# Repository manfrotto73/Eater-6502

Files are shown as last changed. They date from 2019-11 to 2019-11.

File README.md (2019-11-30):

# Eater-6502
This is a KiCad project that follows Ben Eater's 6502 video series (https://eater.net/6502). I designed the PCB from Ben's schematic.

DISCLAIMER: I am not an EE or a professional PCB designer. I am just a hobbyist who enjoys tinkering w/ electronics and computers. I have no formal training in electrical engineering. Any constructive and educational input is much appreciated.

I have addedd test points on the address and data bus for attaching the Arduino monitor.
The clock has a jumper for access to the internal 1MHz crystal or you can remove the jumper and use Ben's breadboard clock. I also have a pcb for the clock if needed (https://github.com/manfrotto73/Eater-Clock).
There is access to the 8 port "B" lines of the 6522 to attach LED's or a oscilloscope to decode the LCD data if needed. There is a footprint for a current limiting resistor pack (220R) so the LED's will not draw too much current.
I intend to socket all IC's and LED's for ease of troubleshooting or ROM update. Also the LED's are only for the first couple of programs.
Enjoy!
11/29/2019 Schematic and PCB updated to pull the BE pin high to +5V

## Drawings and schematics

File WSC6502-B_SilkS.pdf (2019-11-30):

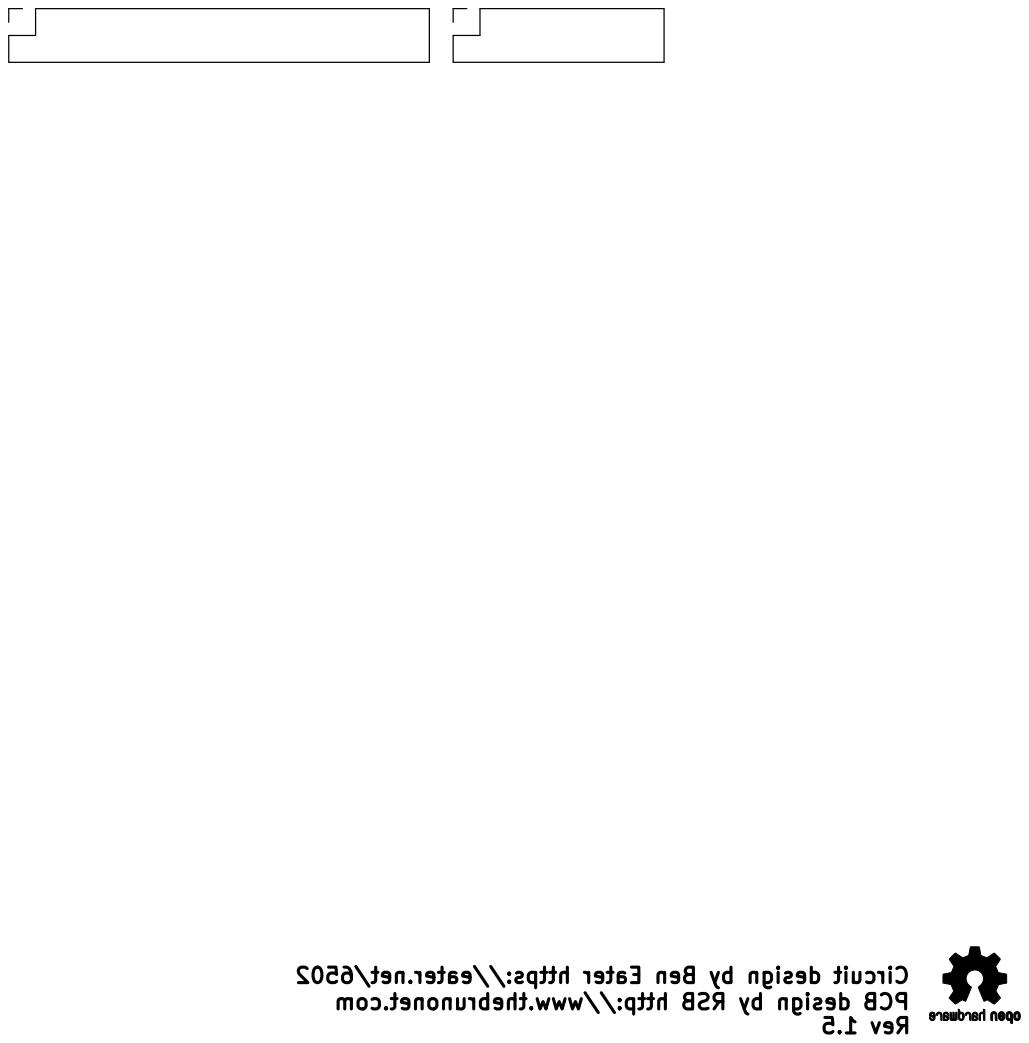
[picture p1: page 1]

Rev 1.5 Circuit design by Ben Eater https://eater.net/6502

PCB design by RSB http://www.thebrunonet.com

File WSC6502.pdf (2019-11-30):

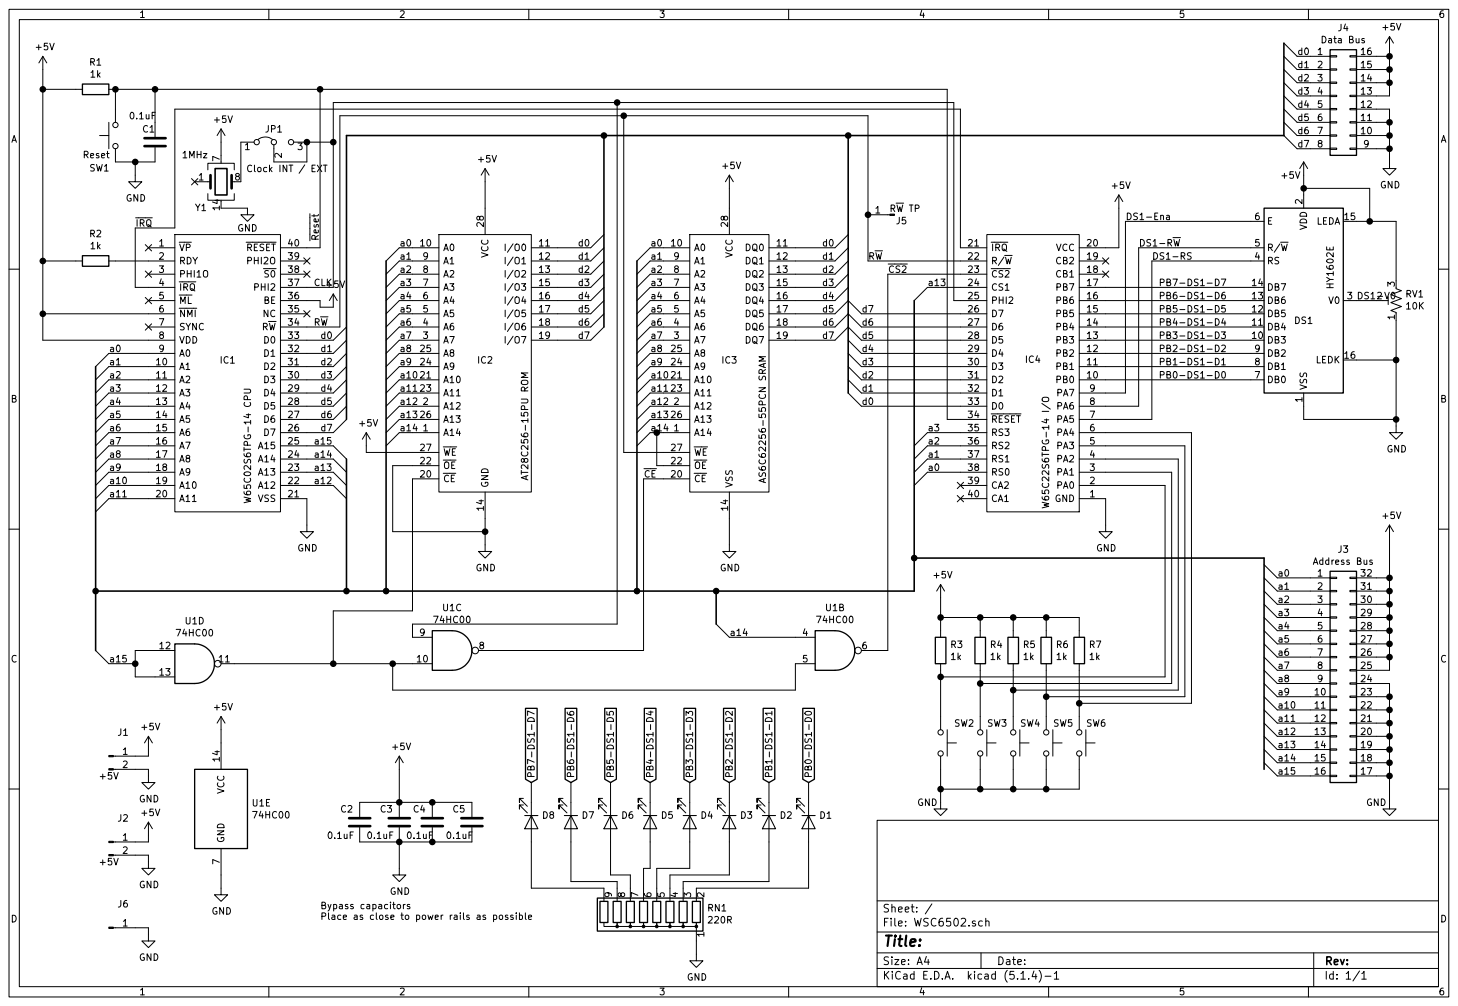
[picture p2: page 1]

Id: 1/1 Title: File: WSC6502.sch Sheet: / D7 GND GND

Place as close to power rails as possible

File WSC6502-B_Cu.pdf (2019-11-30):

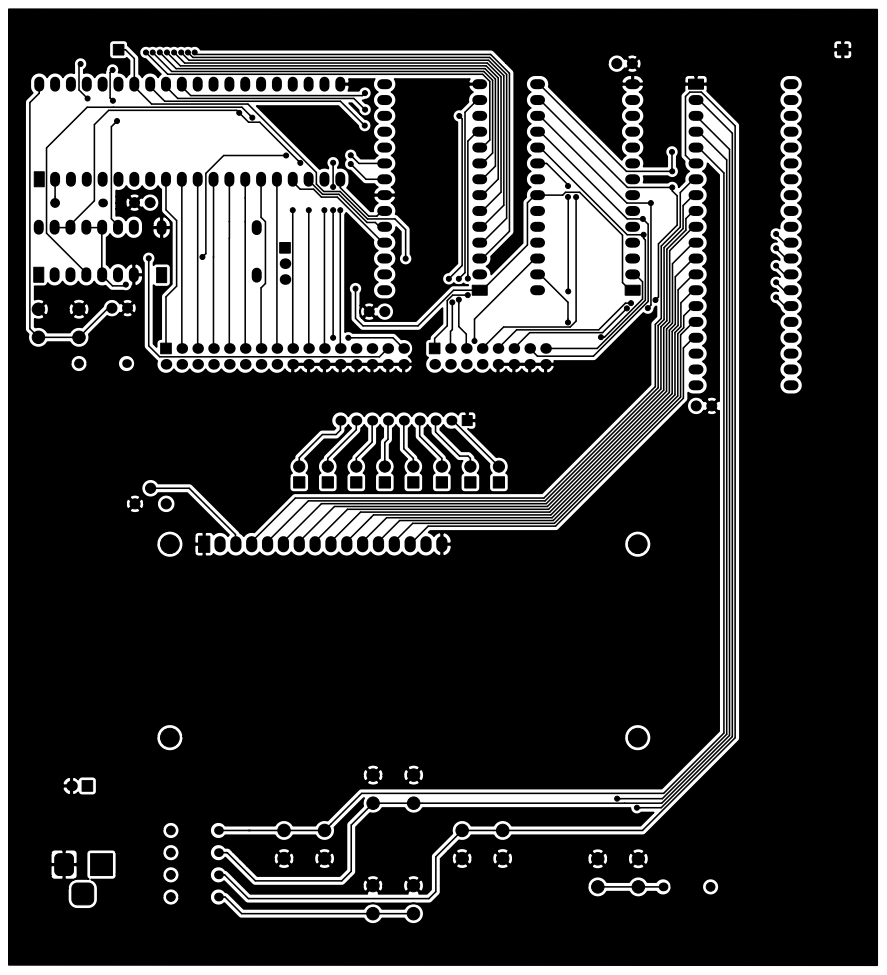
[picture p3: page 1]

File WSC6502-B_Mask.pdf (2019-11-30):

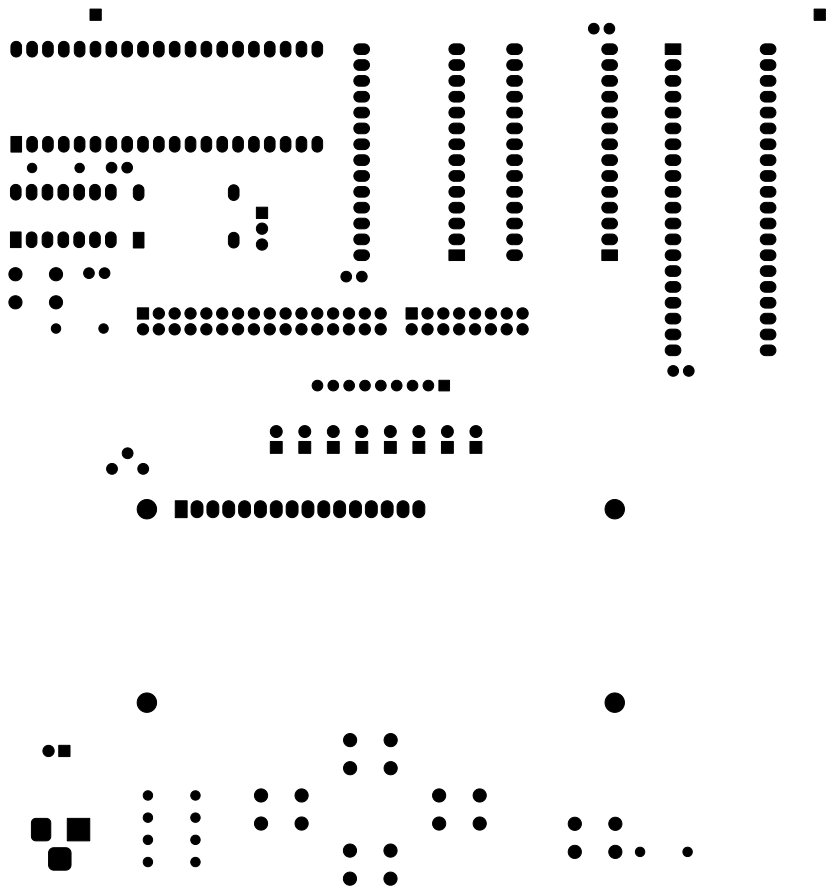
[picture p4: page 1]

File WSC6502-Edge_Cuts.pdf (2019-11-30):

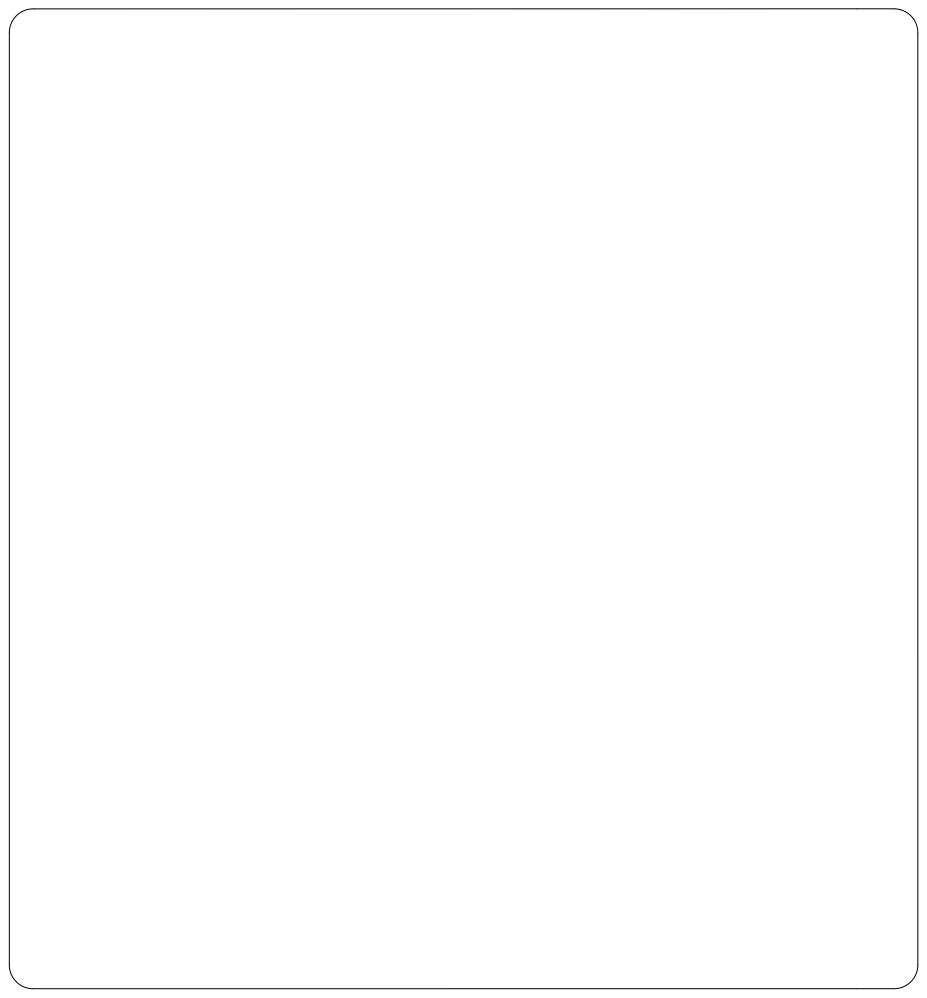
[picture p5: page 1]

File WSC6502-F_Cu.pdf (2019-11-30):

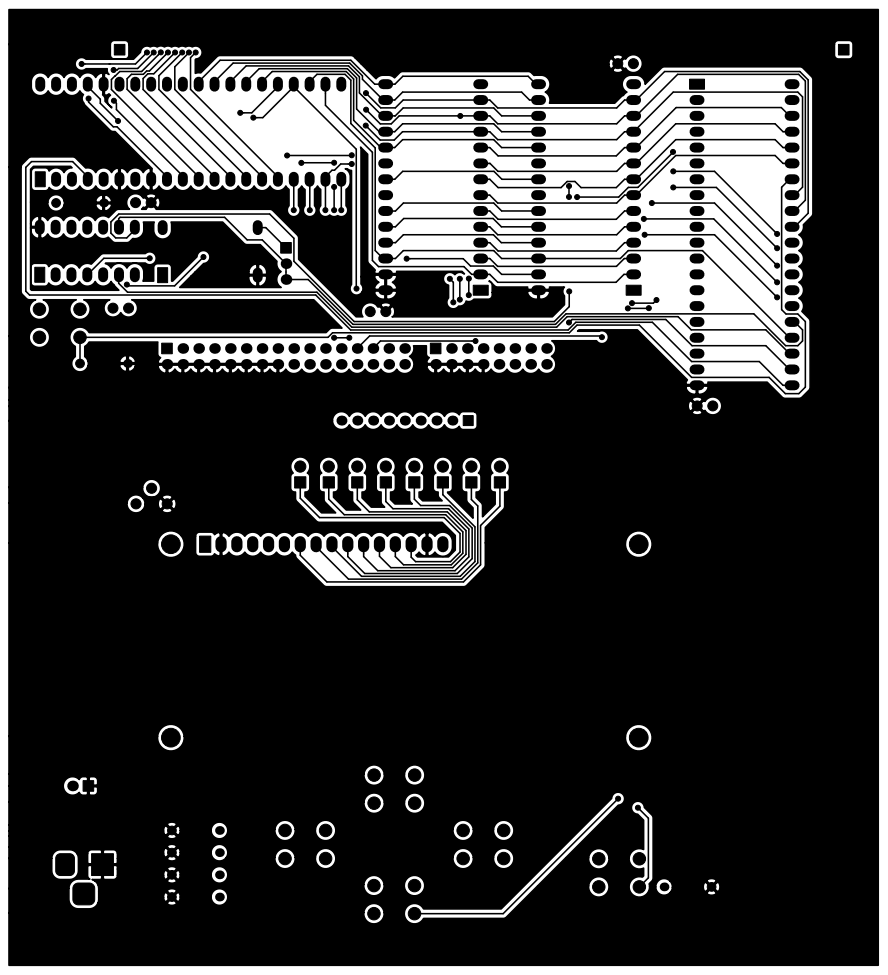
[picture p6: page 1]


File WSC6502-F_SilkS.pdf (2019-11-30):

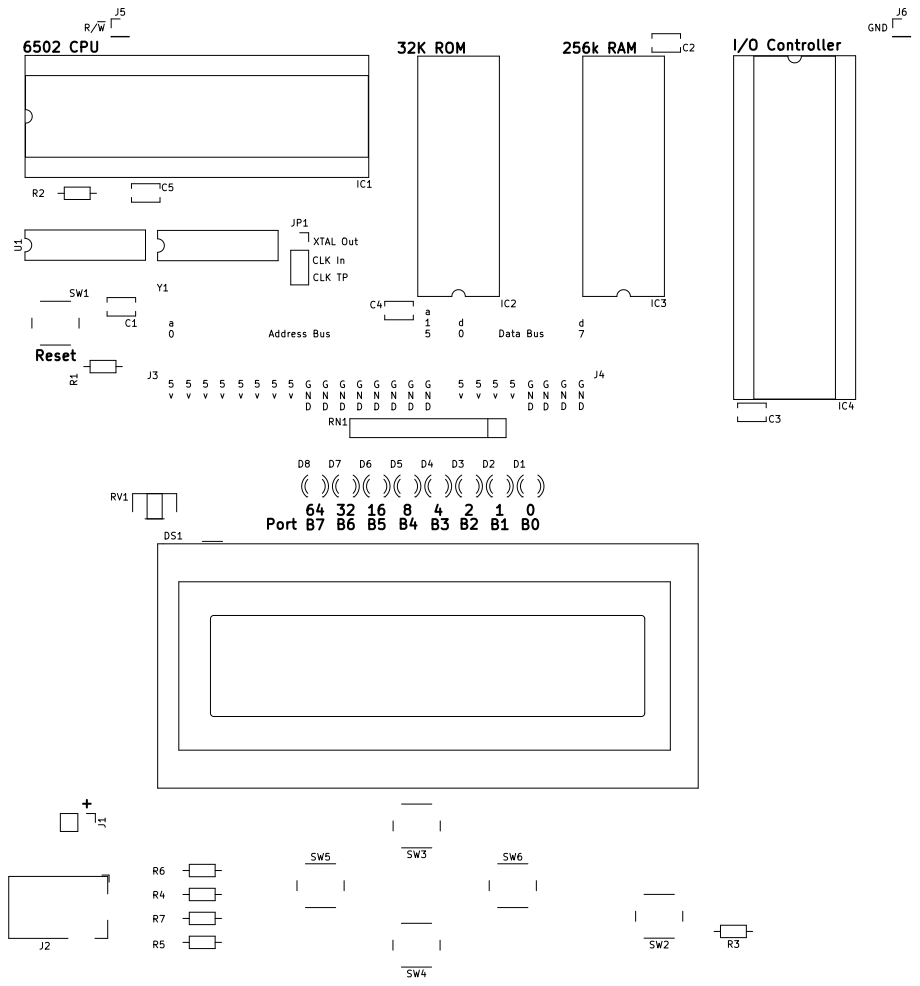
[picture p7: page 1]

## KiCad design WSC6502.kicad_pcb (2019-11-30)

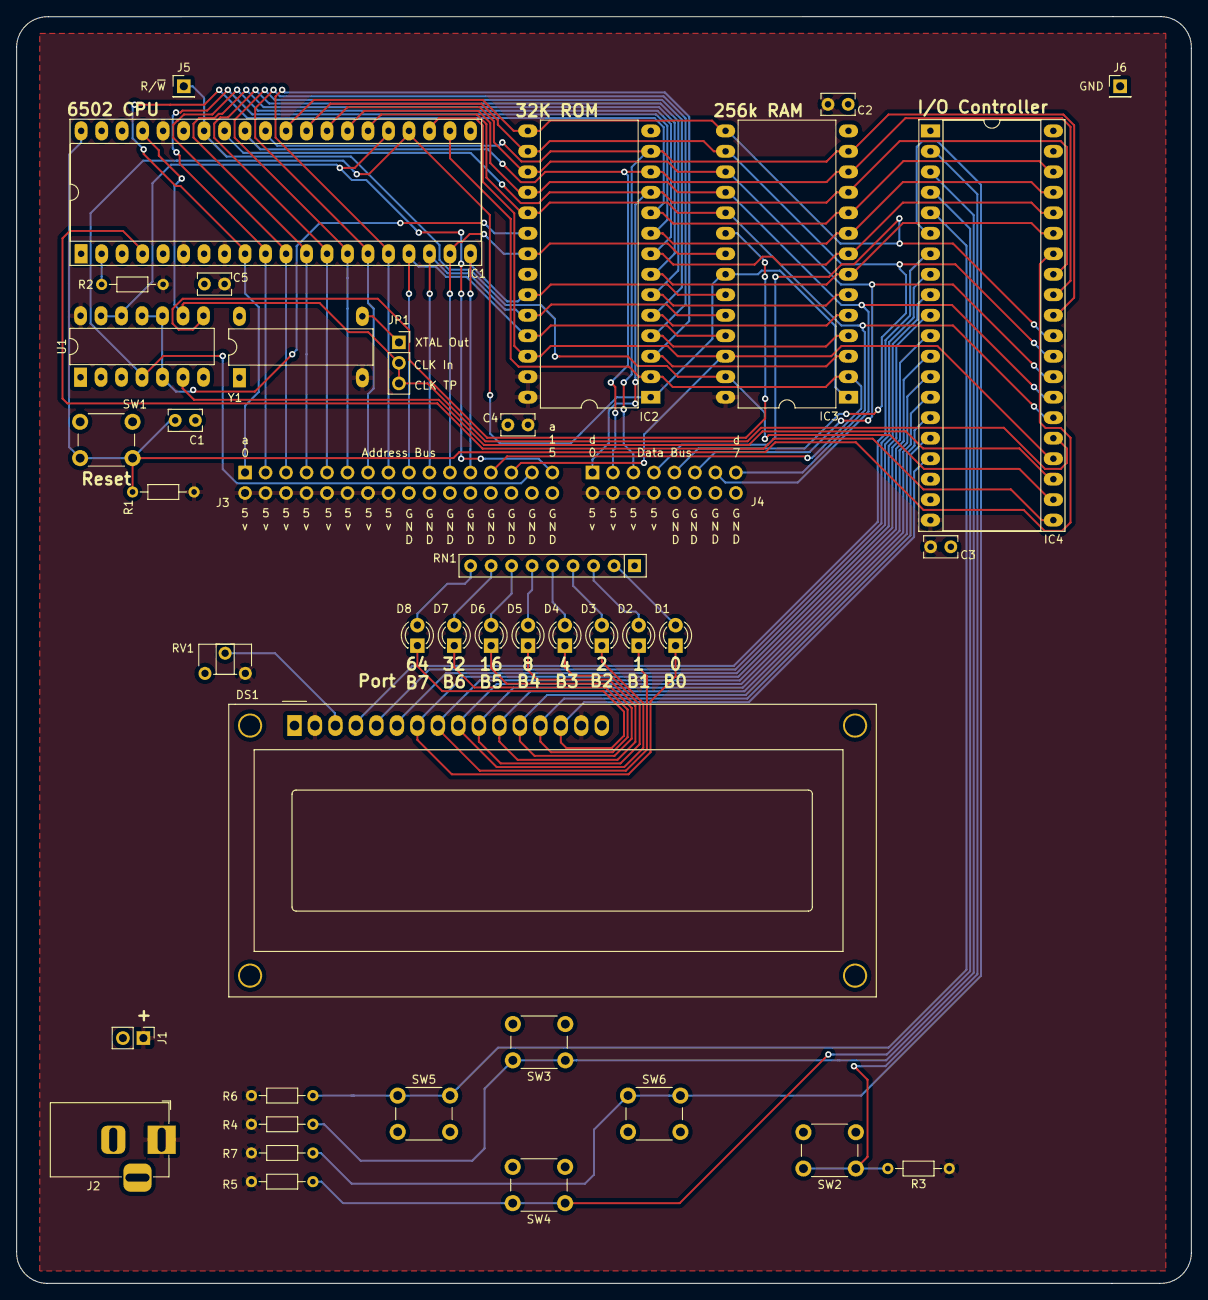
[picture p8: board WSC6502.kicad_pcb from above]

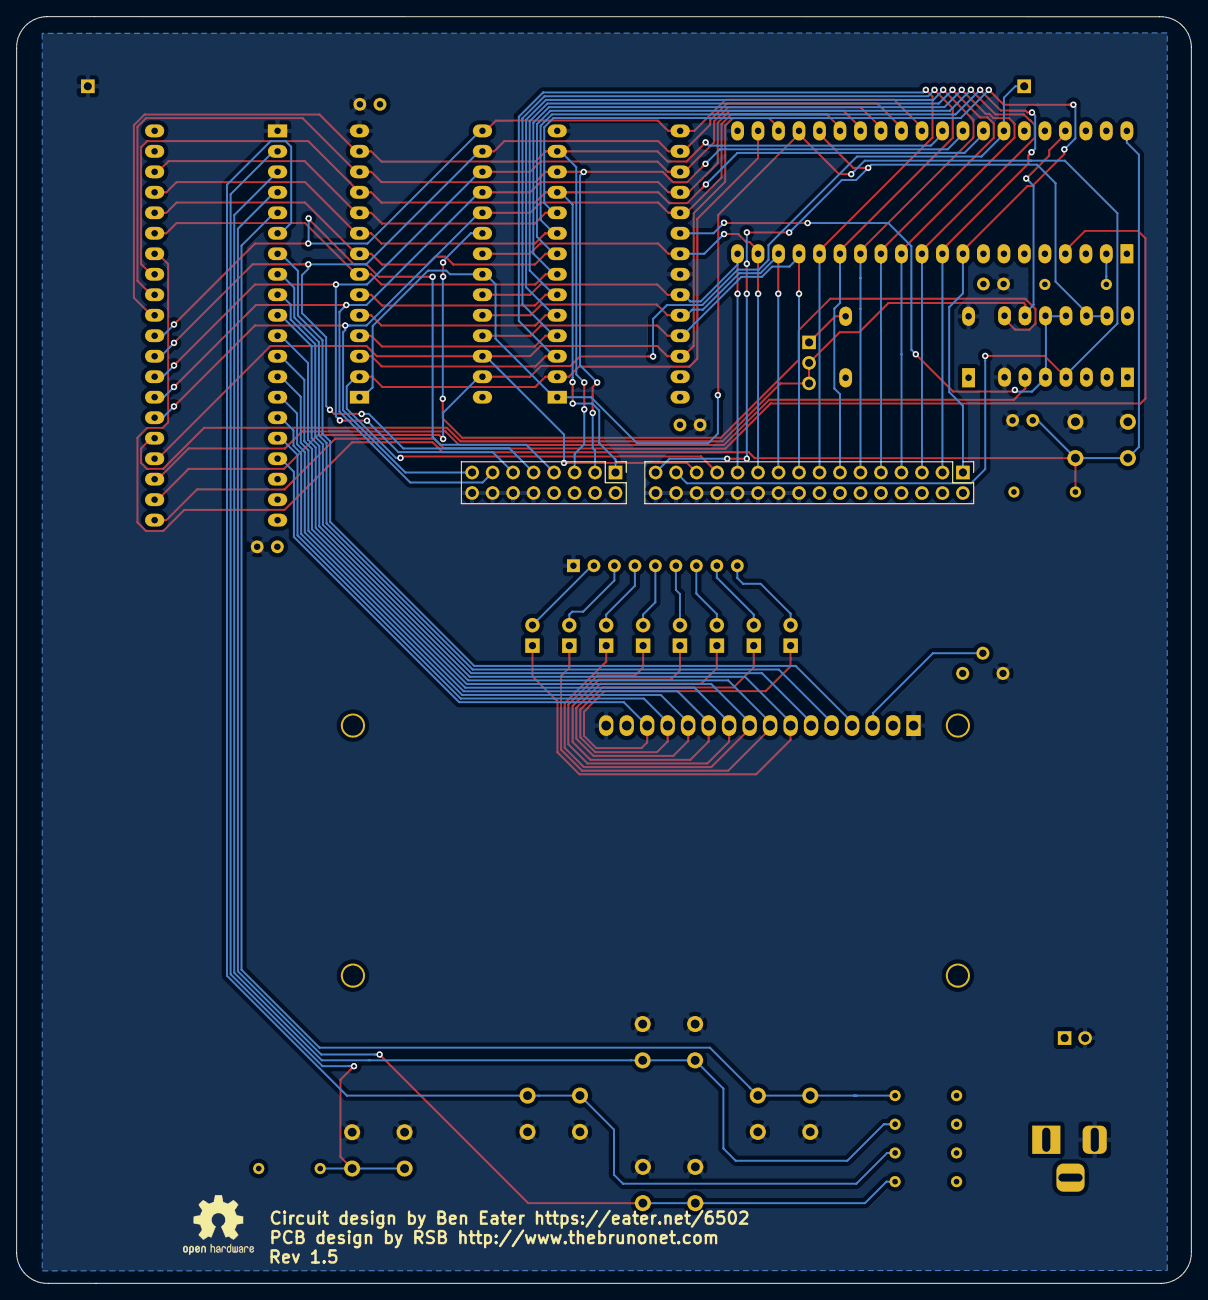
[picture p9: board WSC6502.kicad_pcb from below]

Board: 2 copper layers, 145.6 x 157.0 mm, 42 parts (2 on the bottom side), 60 nets.

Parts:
C1, C2, C3, C4, C5: 0.1uF; C_Rect_L4.0mm_W2.5mm_P2.50mm
D1, D2, D3, D4, D5, D6, D7, D8: LED_D3.0mm
DS1: HY1602E; WC1602A
IC1: W65C02S6TPG-14 CPU; DIP-40_W15.24mm_Socket_LongPads
IC2: AT28C256-15PU ROM; DIP-28_W15.24mm_LongPads
IC3: AS6C62256-55PCN SRAM; DIP-28_W15.24mm_LongPads
IC4: W65C22S6TPG-14 I/O; DIP-40_W15.24mm_Socket_LongPads
J1: +5V; PinHeader_1x02_P2.54mm_Vertical
J2: +5V; BarrelJack_Horizontal
J3: Address Bus; PinHeader_2x16_P2.54mm_Vertical
J4: Data Bus; PinHeader_2x08_P2.54mm_Vertical
J5: R~W~ TP; PinHeader_1x01_P2.54mm_Vertical
J6: PinHeader_1x01_P2.54mm_Vertical
JP1: Clock INT / EXT; PinSocket_1x03_P2.54mm_Vertical
R1, R2, R3, R4, R5, R6, R7: 1k; R_Axial_DIN0204_L3.6mm_D1.6mm_P7.62mm_Horizontal
RN1: 220R; R_Array_SIP9
RV1: 10K; Potentiometer_ACP_CA6-H2,5_Horizontal
SW1: Reset; SW_PUSH_6mm_H5mm
SW2, SW3, SW4, SW5, SW6: SW_PUSH_6mm_H5mm
U1: 74HC00; DIP-14_W7.62mm_LongPads
Y1: 1MHz; DIP-14_W7.62mm_LongPads

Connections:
+5V: C2.1, C3.1, C4.1, C5.1, DS1.2, DS1.15, IC1.6, IC1.8, IC1.36, IC2.27, IC2.28, IC3.28, IC4.20, J1.1, J2.1, J3.25, J3.26, J3.27, J3.28, J3.29, J3.30, J3.31, J3.32, J4.13, J4.14, J4.15, J4.16, R1.2, R2.2, R3.1, R4.1, R5.1, R6.1, R7.1, RV1.3, U1.14, Y1.7
/CLK: IC1.37, IC4.25, JP1.2, JP1.3, U1.9
/DS1-Ena: DS1.6, IC4.9
/DS1-RS: DS1.4, IC4.7
/DS1-R~W: DS1.5, IC4.8
/DS1-V0: DS1.3, RV1.2
/R~W: IC1.34, IC3.27, IC4.22, J5.1
/a0: IC1.9, IC2.10, IC3.10, IC4.38, J3.1
/a1: IC1.10, IC2.9, IC3.9, IC4.37, J3.2
/a2: IC1.11, IC2.8, IC3.8, IC4.36, J3.3
/a3: IC1.12, IC2.7, IC3.7, IC4.35, J3.4
/a4: IC1.13, IC2.6, IC3.6, J3.5
/a5: IC1.14, IC2.5, IC3.5, J3.6
/a6: IC1.15, IC2.4, IC3.4, J3.7
/a7: IC1.16, IC2.3, IC3.3, J3.8
/a8: IC1.17, IC2.25, IC3.25, J3.9
/a9: IC1.18, IC2.24, IC3.24, J3.10
/a10: IC1.19, IC2.21, IC3.21, J3.11
/a11: IC1.20, IC2.23, IC3.23, J3.12
/a12: IC1.22, IC2.2, IC3.2, J3.13
/a13: IC1.23, IC2.26, IC3.26, IC4.24, J3.14
/a14: IC1.24, IC2.1, IC3.1, IC3.22, J3.15, U1.4
/a15: IC1.25, J3.16, U1.12, U1.13
/d0: IC1.33, IC2.11, IC3.11, IC4.33, J4.1
/d1: IC1.32, IC2.12, IC3.12, IC4.32, J4.2
/d2: IC1.31, IC2.13, IC3.13, IC4.31, J4.3
/d3: IC1.30, IC2.15, IC3.15, IC4.30, J4.4
/d4: IC1.29, IC2.16, IC3.16, IC4.29, J4.5
/d5: IC1.28, IC2.17, IC3.17, IC4.28, J4.6
/d6: IC1.27, IC2.18, IC3.18, IC4.27, J4.7
/d7: IC1.26, IC2.19, IC3.19, IC4.26, J4.8
/~CE~: IC3.20, U1.8
/~CS2~: IC4.23, U1.6
/~IRQ~: IC1.4, IC4.21
/~Reset: C1.1, IC1.40, IC4.34, R1.1, SW1.2
GND: C1.2, C2.2, C3.2, C4.2, C5.2, DS1.1, DS1.16, IC1.21, IC2.14, IC2.22, IC3.14, IC4.1, J1.2, J2.2, J3.17, J3.18, J3.19, J3.20, J3.21, J3.22, J3.23, J3.24, J4.9, J4.10, J4.11, J4.12, J6.1, RN1.1, RV1.1, SW1.1, SW2.2, SW3.2, SW4.2, SW5.2, SW6.2, U1.7, Y1.14
unnamed: D1.2, RN1.2
unnamed: D2.2, RN1.3
unnamed: D3.2, RN1.4
unnamed: D4.2, RN1.5
unnamed: D5.2, RN1.6
unnamed: D6.2, RN1.7
unnamed: D7.2, RN1.8
unnamed: D8.2, RN1.9
unnamed: IC1.2, R2.1
unnamed: IC2.20, U1.5, U1.10, U1.11
unnamed: IC4.2, R3.2, SW2.1
unnamed: IC4.3, R4.2, SW3.1
unnamed: IC4.4, R5.2, SW4.1
unnamed: IC4.5, R6.2, SW5.1
unnamed: IC4.6, R7.2, SW6.1
unnamed: JP1.1, Y1.8
PB0-DS1-D0: D1.1, DS1.7, IC4.10
PB1-DS1-D1: D2.1, DS1.8, IC4.11
PB2-DS1-D2: D3.1, DS1.9, IC4.12
PB3-DS1-D3: D4.1, DS1.10, IC4.13
PB4-DS1-D4: D5.1, DS1.11, IC4.14
PB5-DS1-D5: D6.1, DS1.12, IC4.15
PB6-DS1-D6: D7.1, DS1.13, IC4.16
PB7-DS1-D7: D8.1, DS1.14, IC4.17

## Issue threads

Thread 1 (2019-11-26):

PDF

Upcycle-Electronics, 2019-11-26:
Export your files as a PDF so others can view what you've done easier. For instance, I'm usually not on a computer when surfing the web socially. While I am on KiCAD regularly, I'm usually working on my own stuff. I can't view your files from a tablet. Also, you might mention your design specs like board size, layers, etc. I've seen a bunch of people building stuff for Ben's project, but I'm curious if anyone is actually etching boards themselves. I got around 90% done with a 6502 design for DIY etching a few weeks ago, (not uploaded). I'm not going to etch until I have a TL866 and/or have a working USB to UART interface. Anyways...good luck with it.
-Jake

manfrotto73, 2019-12-03:
PDF files have been uploaded

Closed 2019-12-03.

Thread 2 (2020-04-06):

Crystal polarity error

Norlin76, 2020-04-06:
Pin 7 is connected to +5V and should be connected to ground
Pin 14 is connected to ground and should be connected to +5V

I've temporarily fixed by putting the crystal in rotated 180 degrees and jumpering pins 1 and 8 together.
